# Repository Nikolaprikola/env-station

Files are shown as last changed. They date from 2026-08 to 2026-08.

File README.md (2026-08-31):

# ESP32-C3 Environmental Monitoring Station

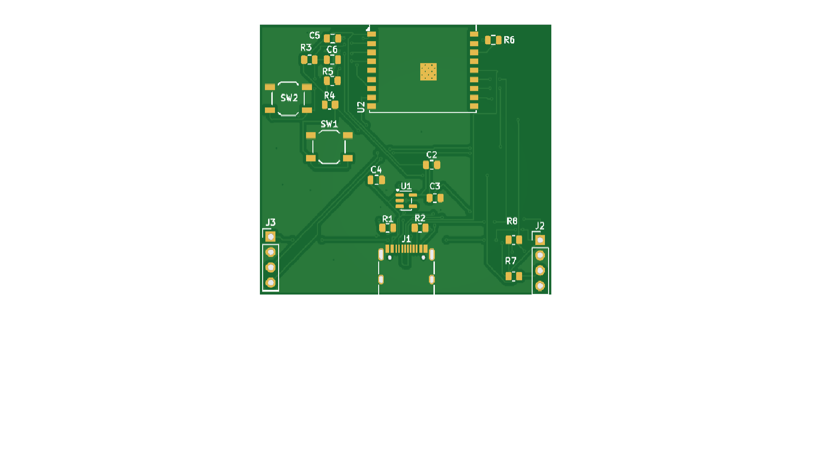
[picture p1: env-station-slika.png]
PCB


Dvoslojna PCB za mjerenje temperature, vlage, tlaka, CO2 i
cestica. Prvi vlastiti PCB dizajn.

## Hardver
- ESP32-C3-WROOM-02
- AP2112K-3.3 LDO, napajanje preko USB-C
- I2C header (BME280, SCD40)
- UART header (PMS5003)
- Boot i reset tipke

## Status
Rev A - dizajn zavrsen, DRC cist, ploca jos nije proizvedena.

## Alati
KiCad 10

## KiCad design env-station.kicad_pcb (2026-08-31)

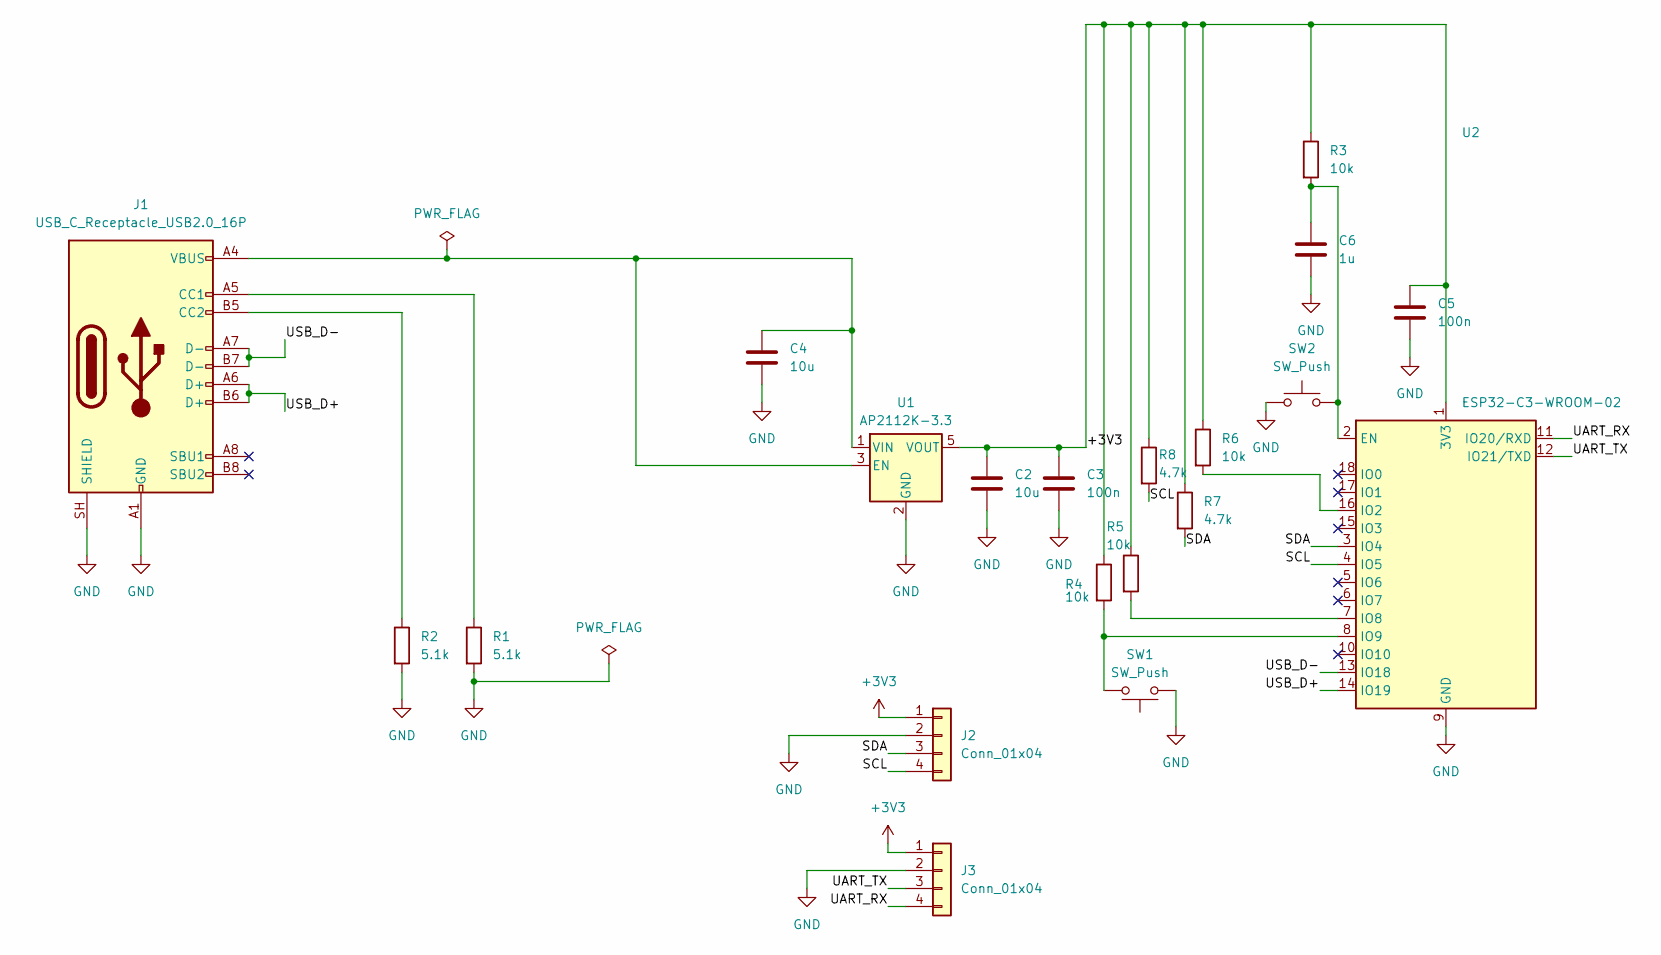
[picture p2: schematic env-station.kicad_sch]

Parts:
C2, C4: 10u; C_0805_2012Metric
C3, C5: 100n; C_0805_2012Metric
C6: 1u; C_0805_2012Metric
J1: USB_C_Receptacle_USB2.0_16P; USB_C_Receptacle_HRO_TYPE-C-31-M-12
J2, J3: Conn_01x04; PinHeader_1x04_P2.54mm_Vertical
R1, R2: 5.1k; R_0805_2012Metric
R3, R4, R5, R6: 10k; R_0805_2012Metric
R7, R8: 4.7k; R_0805_2012Metric
SW1, SW2: SW_Push; SW_SPST_TL3342
U1: AP2112K-3.3; SOT-23-5
U2: ESP32-C3-WROOM-02

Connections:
+3V3: C2.1, C3.1, C5.1, J2.1, J3.1, R3.1, R4.1, R5.1, R6.1, R7.1, R8.1, U1.5 (VOUT), U2.1 (3V3)
/SCL: J2.4, R8.2, U2.4 (IO5)
/SDA: J2.3, R7.2, U2.3 (IO4)
/UART_RX: J3.4, U2.11 (IO20/RXD)
/UART_TX: J3.3, U2.12 (IO21/TXD)
/USB_D+: J1.A6 (D+), J1.B6 (D+), U2.14 (IO19)
/USB_D-: J1.A7 (D-), J1.B7 (D-), U2.13 (IO18)
GND: C2.2, C3.2, C4.2, C5.2, C6.2, J1.A1 (GND), J1.A12 (GND), J1.B1 (GND), J1.B12 (GND), J1.SH (SHIELD), J2.2, J3.2, R1.2, R2.2, SW1.1, SW2.1, U1.2 (GND), U2.9 (GND), U2.19 (GND)
unnamed: J1.A5 (CC1), R1.1
unnamed: J1.B5 (CC2), R2.1
unnamed: C4.1, J1.A4 (VBUS), J1.A9 (VBUS), J1.B4 (VBUS), J1.B9 (VBUS), U1.1 (VIN), U1.3 (EN)
unnamed: C6.1, R3.2, SW2.2, U2.2 (EN)
unnamed: R6.2, U2.16 (IO2)
unnamed: R5.2, U2.7 (IO8)
unnamed: R4.2, SW1.2, U2.8 (IO9)

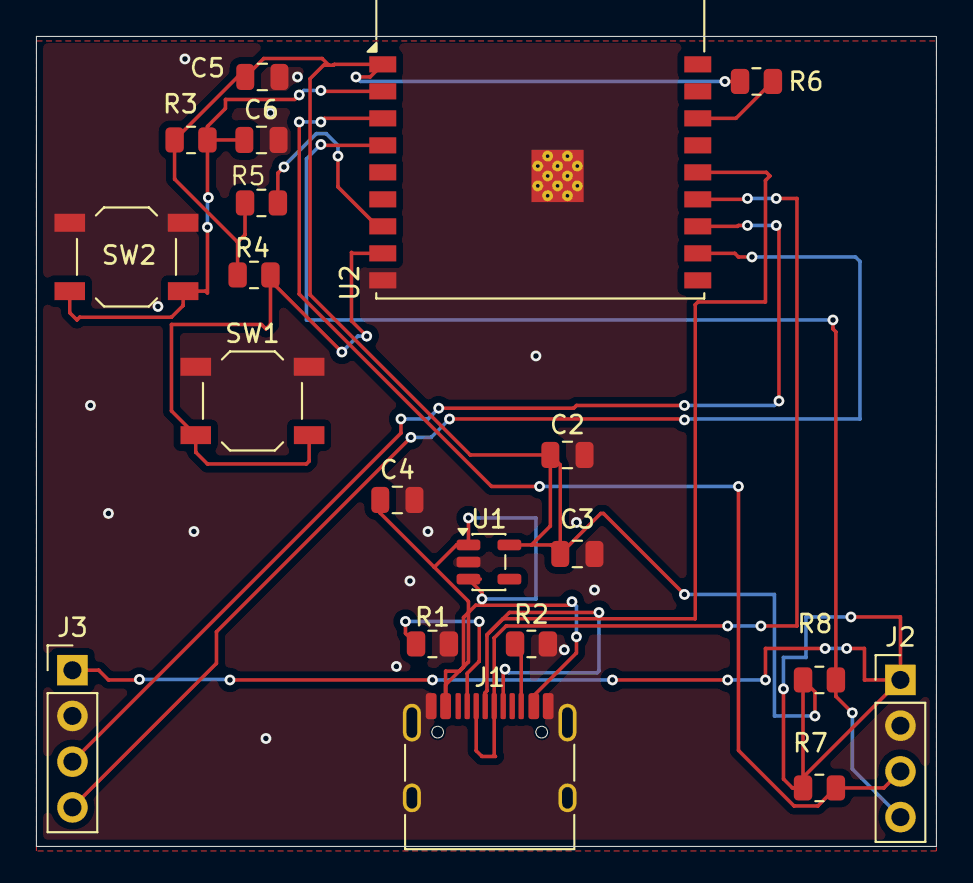
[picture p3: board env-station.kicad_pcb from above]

Board: 2 copper layers, 50.0 x 45.0 mm, 20 parts (0 on the bottom side), 15 nets.

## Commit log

2026-08-31 Rev A - shema i layout
    [env-station-B_Cu.gbr, env-station-B_Mask.gbr, env-station-B_Paste.gbr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]
2026-08-31 Add README for ESP32-C3 Environmental Monitoring Station
2026-08-31 Dodan NPTH drill file
    [env-station-NPTH.drl]
2026-08-31 Include PCB image in README
    Added an image of the PCB to the README.
